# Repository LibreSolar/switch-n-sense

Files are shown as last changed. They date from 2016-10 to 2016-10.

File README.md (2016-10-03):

# Switch-N-Sense
High-side NMOS power switch and current sense resistor for battery applications

This device is the power part of the new generation Libre Solar 24V-48V BMS, but can also be used for lead-acid battery protection switches.

The connector to the BMS (IDC connector) is placed at the same height as in the BMS PCB. So mount this PCB right next to the BMS PCB (right side).

## Design considerations

The MOSFETs and the sense resistors are mounted at the back side of the PCB and should be attached to a large heat sink via thermal interface materials (e.g. thermal pad).

[Würth Power Elements WP-BUCF (order code 7461059)](https://powerelement.we-online.de/p/s/1406/93172-PowerOne-Bush-vertical-through-hole.html) are used for wire to board connection.

## Current target

Current rating can be adjusted depending on chosen MOSFETs and sense resistors.

- Maximum number of MOSFETs: 2 in parallel
- Maximum number of sense resitors (2512): 4

Targets for fully populated PCB (total heat dissipation approx. 20 W in MOSFETs, connectors and sense resistor at full current):

| MOSFET (2x) | Voltage | Maximum Current | Remark |
|---|---|---|---|
| FDMT80080DC | 48V | 80 A | |
| FDMT80060DC | 12V/24V | 100 A | |
| CSD18540Q5B | 12V/24V | 60 A | cheap alternative, but needs other footprint |

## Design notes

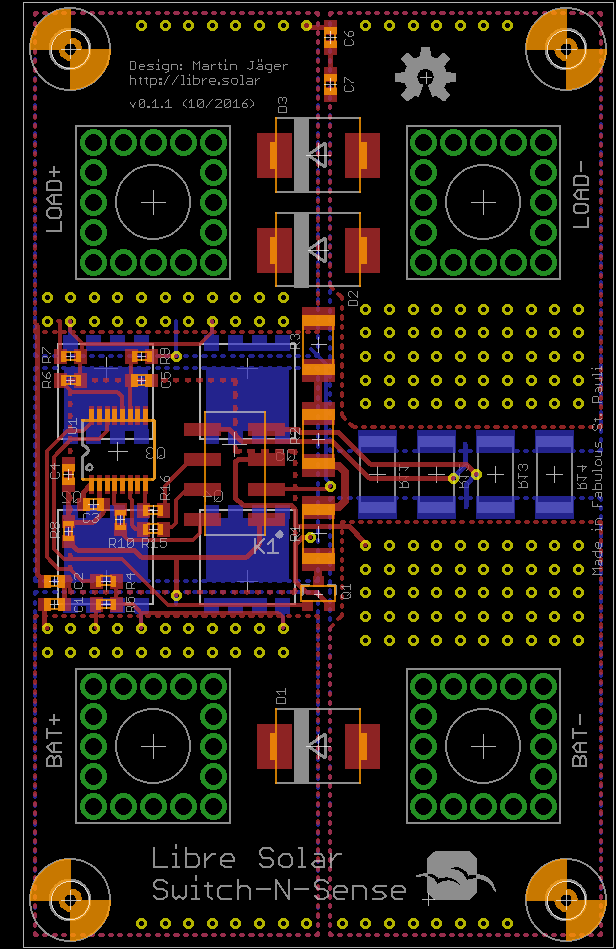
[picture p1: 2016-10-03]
Switch-N-Sense.png

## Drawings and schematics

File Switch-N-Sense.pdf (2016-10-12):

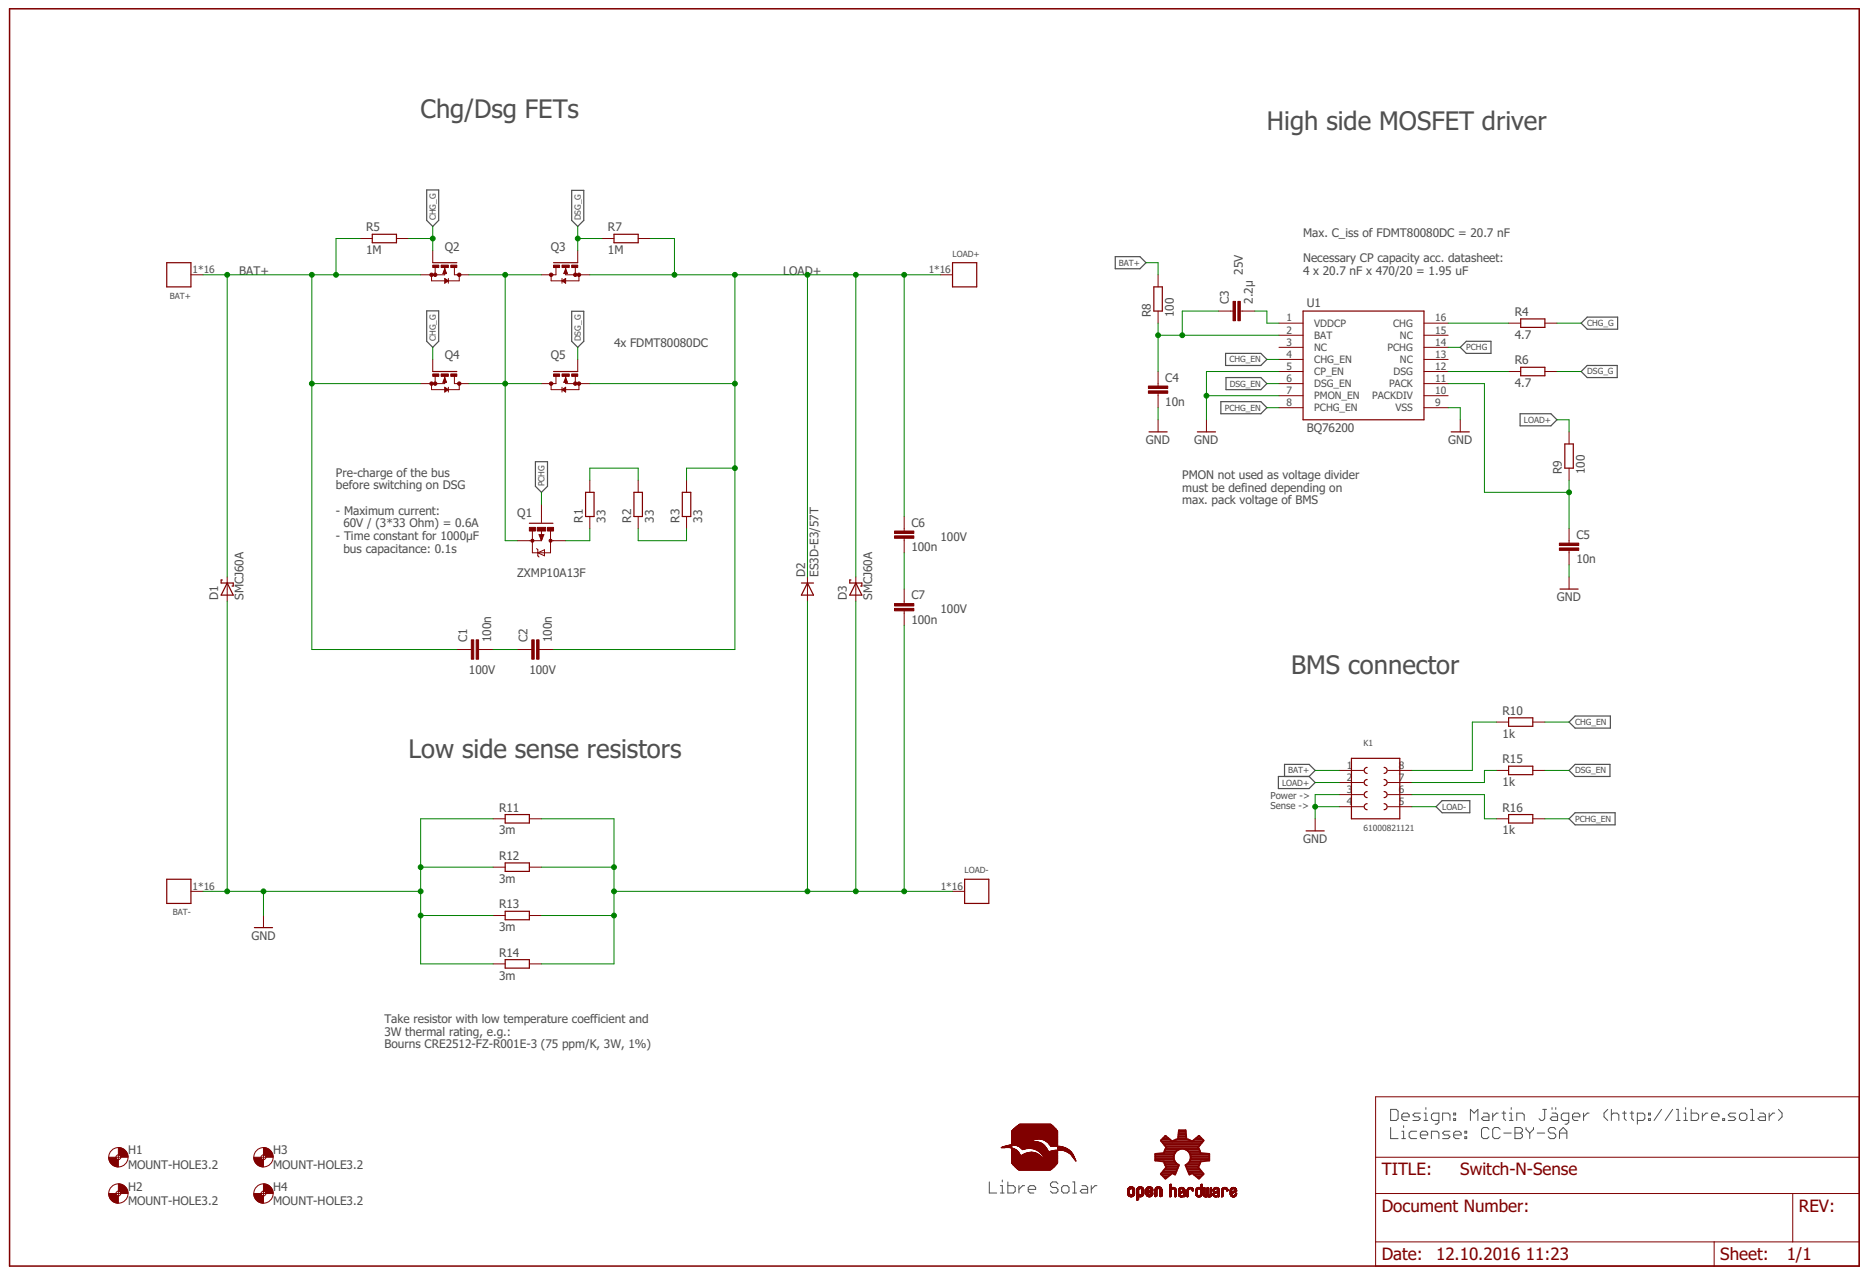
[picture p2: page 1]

Necessary CP capacity acc. datasheet: 4 x 20.7 nF x 470/20 = 1.95 uF

Pre-charge of the bus before switching on DSG

PMON not used as voltage divider must be defined depending on max. pack voltage of BMS

Low side sense resistors

Take resistor with low temperature coefficient and
3W thermal rating, e.g.: Bourns CRE2512-FZ-R001E-3 (75 ppm/K, 3W, 1%)

Document Number: | REV:

Date: 12.10.2016 11:23 | Sheet: 1/1

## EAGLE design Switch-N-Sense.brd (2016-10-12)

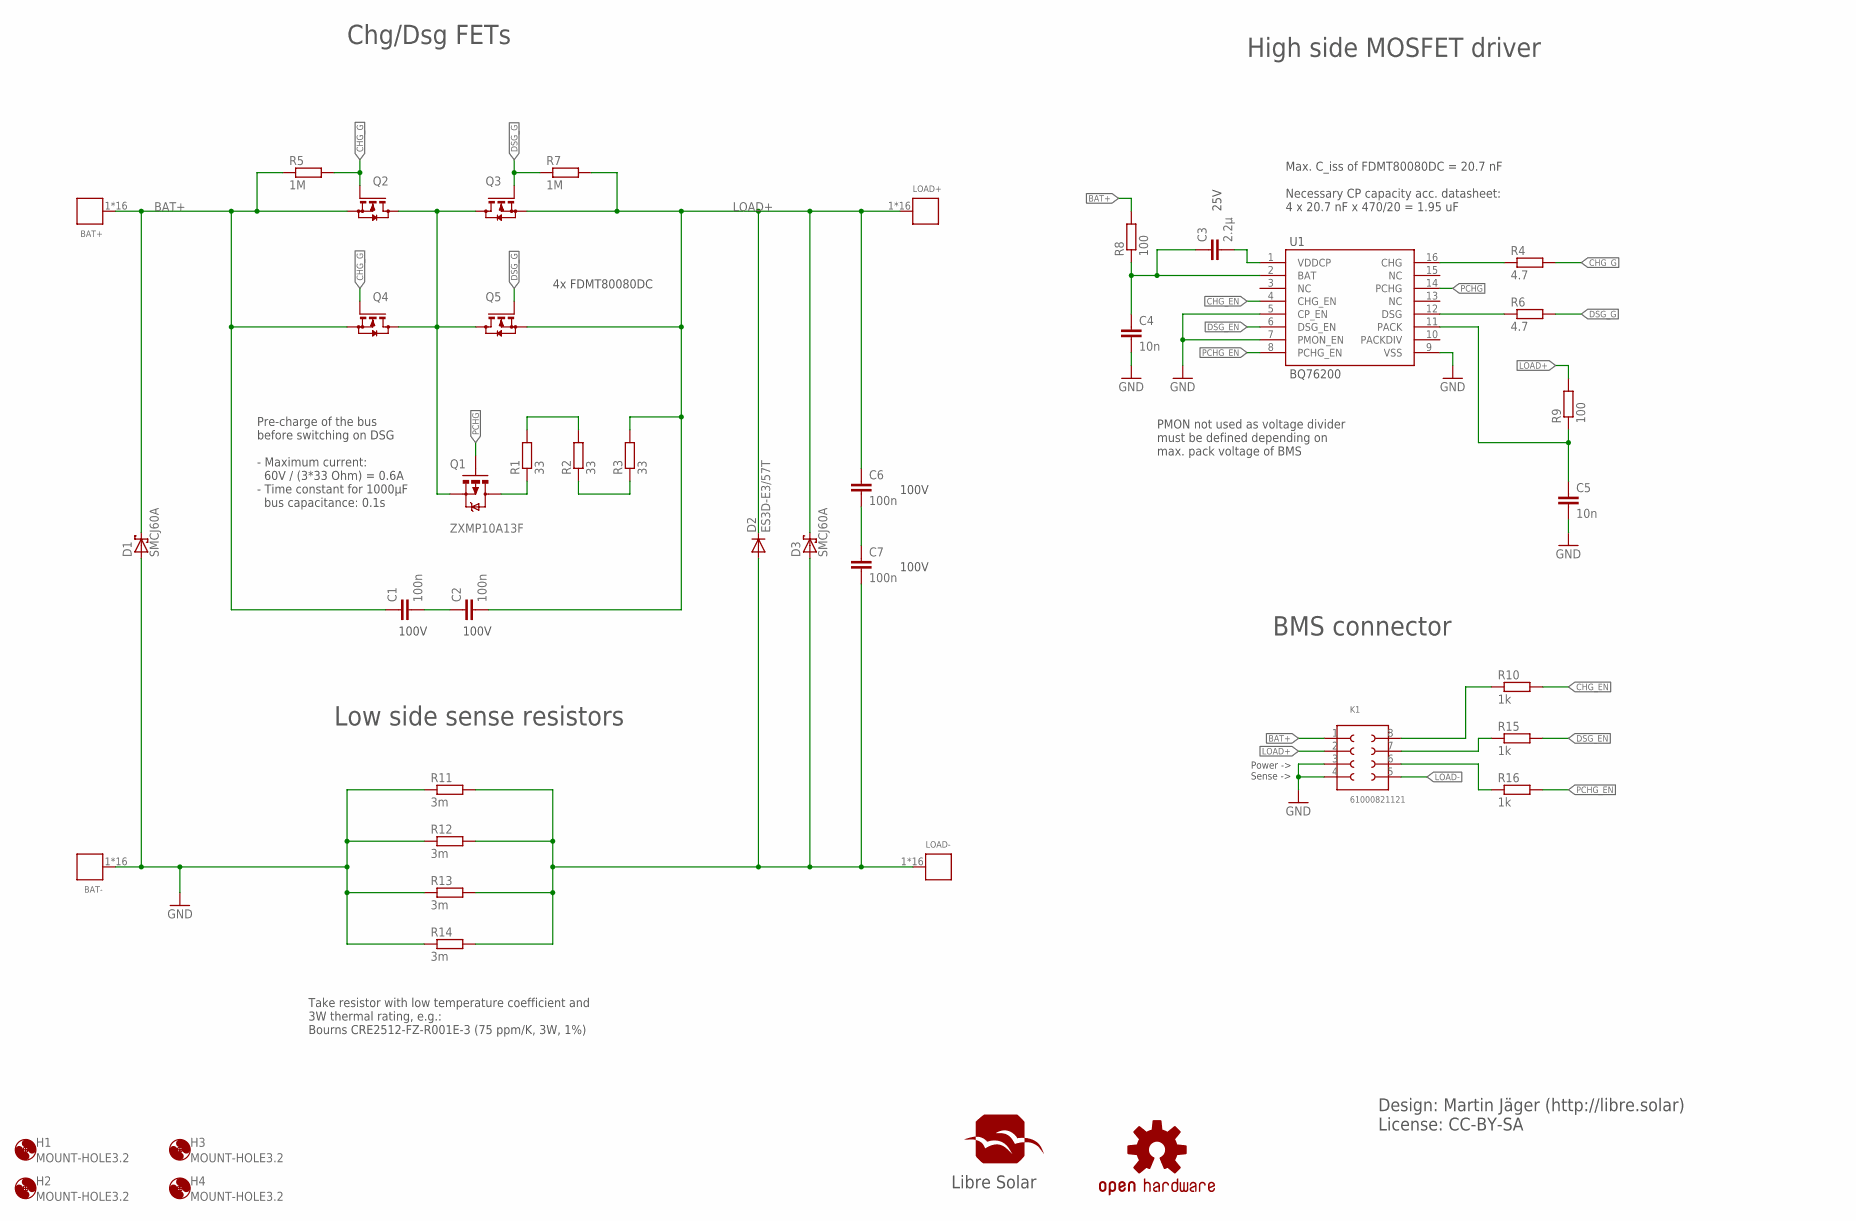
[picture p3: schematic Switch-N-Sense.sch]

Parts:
BAT+: WP-BUCF_G; 16PINS_CIR
BAT-: WP-BUCF_G; 16PINS_CIR
C1, C2, C6, C7: 100n; C0603; MPN 0603B104K500CT
C3: 2.2µ; C0805; MPN 0603B104K500CT
C4, C5: 10n; C0603; MPN GRM188R71H103KA01D.
D1, D3: SMCJ60A; SMC; MPN SMCJ75A
D2: ES3D-E3/57T; SMC; MPN ES3D-E3/57T.
H1, H2, H3, H4: MOUNT-HOLE3.2; 3,2
K1: 61000821121
LOAD+: WP-BUCF_G; 16PINS_CIR
LOAD-: WP-BUCF_G; 16PINS_CIR
N1: OSHW-LOGOM; OSHW-LOGO-M
Q1: ZXMP10A13F; SOT23-3; MPN ZXMP10A13FTA
Q2, Q3, Q4, Q5: FDMT80080DC
R1, R2, R3: 33; R2010; MPN ASC2010-33RFT4
R4, R6: 4.7; R0603; MPN ERJU06F1004V
R5, R7: 1M; R0603; MPN ERJU06F1004V
R8, R9: 100; R0603; MPN MCMR06X1001FTL
R10, R15, R16: 1k; R0603; MPN ERJU06F1004V
R11, R12, R13, R14: 3m; R2512
U1: BQ76200; TSSOP16
U$1: LIBRESOLAR_LOGO

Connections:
BAT+: BAT+.1, BAT+.2, BAT+.3, BAT+.4, BAT+.5, BAT+.6, BAT+.7, BAT+.8, BAT+.9, BAT+.10, BAT+.11, BAT+.12, BAT+.13, BAT+.14, BAT+.15, BAT+.16, C1.1, D1.C, K1.1, Q2.S, Q4.S, R5.1, R8.2
CHG: R4.1, U1.16 (CHG)
CHGDSG: Q1.2 (S), Q2.D, Q3.D, Q4.D, Q5.D
CHG_EN: R10.2, U1.4 (CHG_EN)
CHG_G: Q2.G, Q4.G, R4.2, R5.2
DSG: R6.1, U1.12 (DSG)
DSG_EN: R15.2, U1.6 (DSG_EN)
DSG_G: Q3.G, Q5.G, R6.2, R7.1
GND: BAT-.1, BAT-.2, BAT-.3, BAT-.4, BAT-.5, BAT-.6, BAT-.7, BAT-.8, BAT-.9, BAT-.10, BAT-.11, BAT-.12, BAT-.13, BAT-.14, BAT-.15, BAT-.16, C4.2, C5.2, D1.A, K1.3, K1.4, R11.1, R12.1, R13.1, R14.1, U1.5 (CP_EN), U1.7 (PMON_EN), U1.9 (VSS)
LOAD+: C2.2, C6.1, D2.C, D3.C, K1.2, LOAD+.1, LOAD+.2, LOAD+.3, LOAD+.4, LOAD+.5, LOAD+.6, LOAD+.7, LOAD+.8, LOAD+.9, LOAD+.10, LOAD+.11, LOAD+.12, LOAD+.13, LOAD+.14, LOAD+.15, LOAD+.16, Q3.S, Q5.S, R3.2, R7.2, R9.2
LOAD-: C7.2, D2.A, D3.A, K1.5, LOAD-.1, LOAD-.2, LOAD-.3, LOAD-.4, LOAD-.5, LOAD-.6, LOAD-.7, LOAD-.8, LOAD-.9, LOAD-.10, LOAD-.11, LOAD-.12, LOAD-.13, LOAD-.14, LOAD-.15, LOAD-.16, R11.2, R12.2, R13.2, R14.2
unnamed: C6.2, C7.1
unnamed: R1.2, R2.2
unnamed: R2.1, R3.1
unnamed: K1.7, R15.1
unnamed: K1.6, R16.1
unnamed: K1.8, R10.1
unnamed: C3.2, U1.1 (VDDCP)
unnamed: C3.1, C4.1, R8.1, U1.2 (BAT)
unnamed: C5.1, R9.1, U1.11 (PACK)
unnamed: C1.2, C2.1
unnamed: Q1.3 (D), R1.1
PCHG: Q1.1 (G), U1.14 (PCHG)
PCHG_EN: R16.2, U1.8 (PCHG_EN)

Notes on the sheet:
Pre-charge of the bus before switching on DSG - Maximum current: 60V / (3*33 Ohm) = 0.6A - Time constant for 1000µF bus capacitance: 0.1s
Chg/Dsg FETs
High side MOSFET driver
Design: Martin Jäger (http://libre.solar) License: CC-BY-SA
Max. C_iss of FDMT80080DC = 20.7 nF Necessary CP capacity acc. datasheet: 4 x 20.7 nF x 470/20 = 1.95 uF
4x FDMT80080DC
Take resistor with low temperature coefficient and 3W thermal rating, e.g.: Bourns CRE2512-FZ-R001E-3 (75 ppm/K, 3W, 1%)
Low side sense resistors
BMS connector
Power -> Sense ->
PMON not used as voltage divider must be defined depending on max. pack voltage of BMS
100V
25V

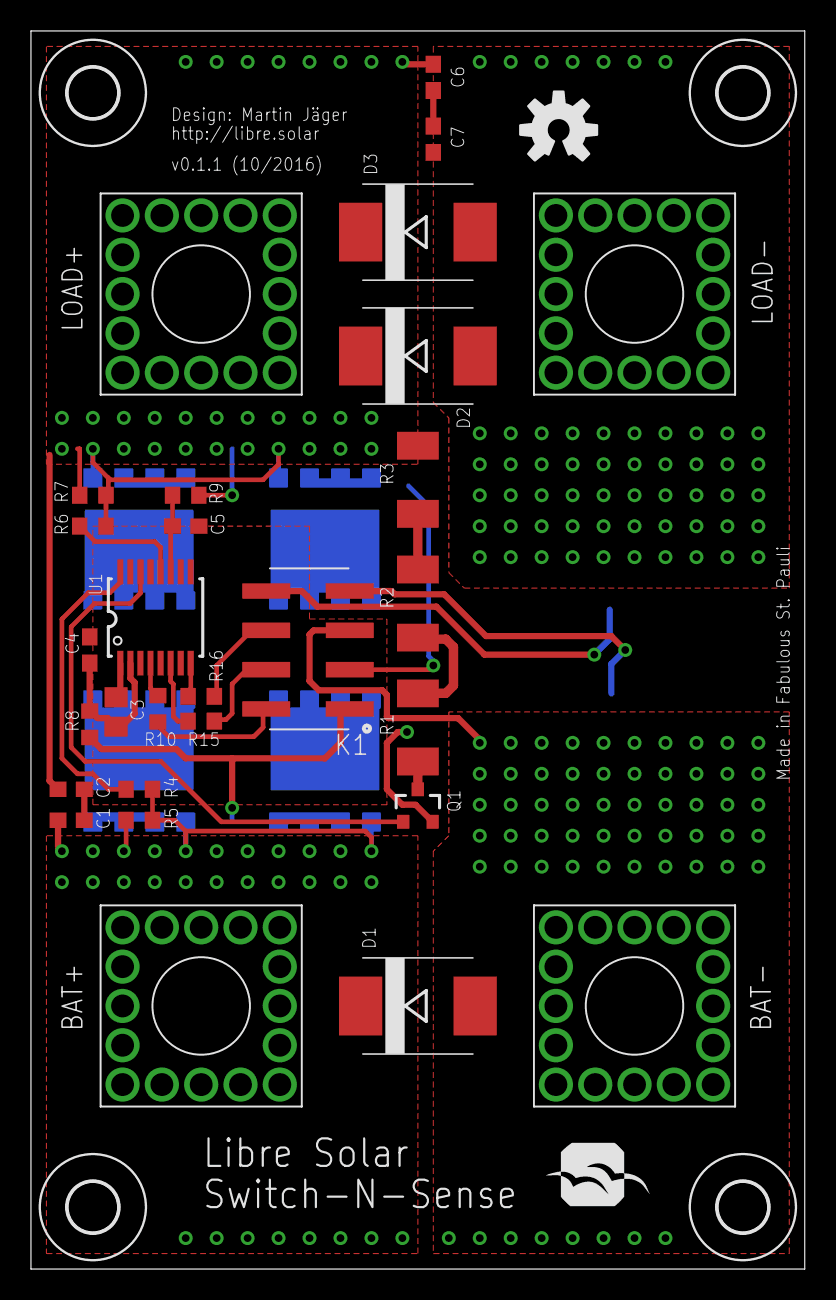
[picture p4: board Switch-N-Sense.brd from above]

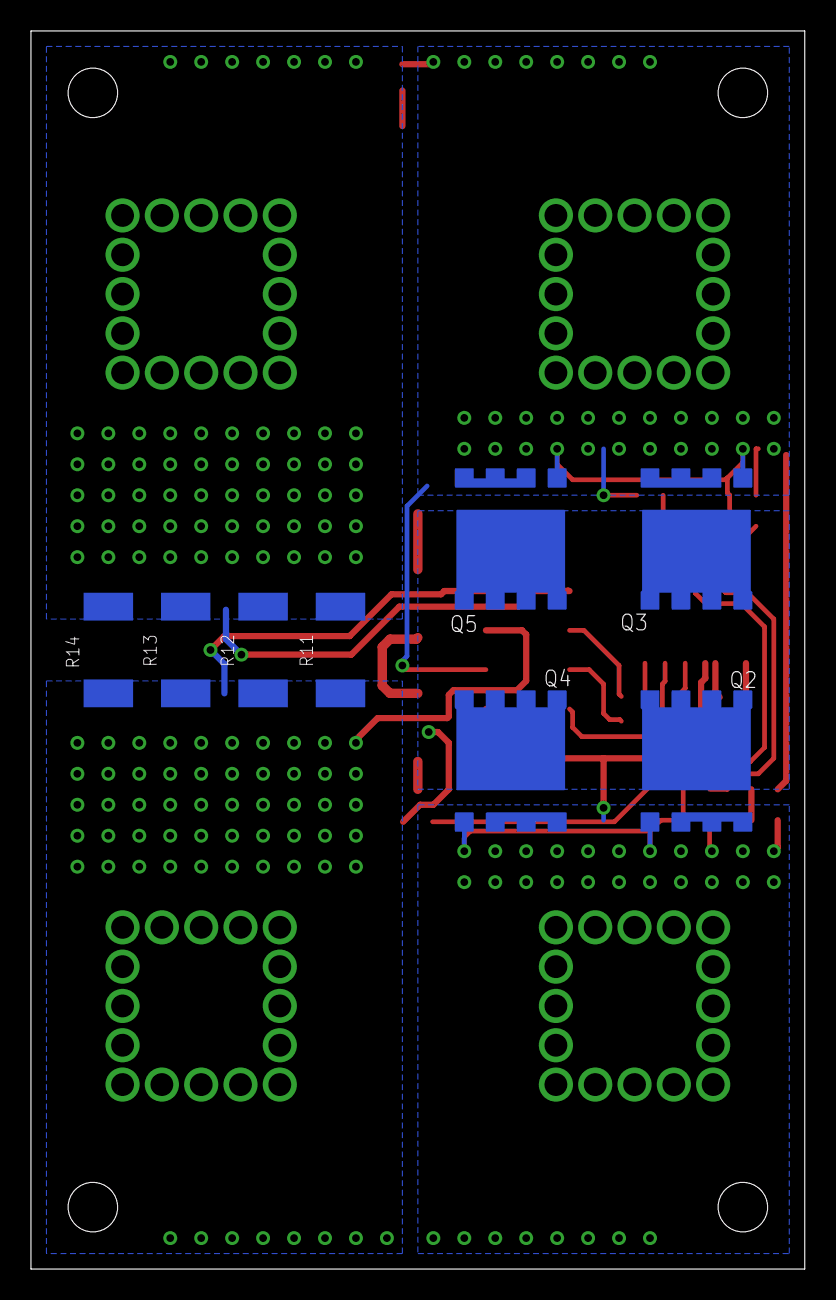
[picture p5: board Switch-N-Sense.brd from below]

Board: 2 copper layers, 50.0 x 80.0 mm, 43 parts (8 on the bottom side), 24 nets.

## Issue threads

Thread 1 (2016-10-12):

Package for C3 (VDDCP capacitor) too small

martinjaeger, 2016-10-12:
For 2.2uF part with 25V rating, at least 0805 package should be used instead of 0603.

martinjaeger, 2016-10-12:
Resolved with commit 094fc36

Closed 2016-10-12.

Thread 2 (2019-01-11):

Increase value of C3

martinjaeger, 2019-01-11:
If two MOSFETs in parallel are used, the value of 2.2 uF is borderline, which caused some issues with switching the MOSFETs during tests.

The capacitor should be increased to 4.7 uF.

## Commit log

2016-08-15 Initial commit of schematic and board
    [Switch-N-Sense.brd, Switch-N-Sense.sch]
2016-10-03 Update to mate with new LibreSolar BMS48V
    [Switch-N-Sense.brd, Switch-N-Sense.sch]
2016-10-12 Updated board and schematic to fix issue #1
    [Switch-N-Sense.brd, Switch-N-Sense.sch]

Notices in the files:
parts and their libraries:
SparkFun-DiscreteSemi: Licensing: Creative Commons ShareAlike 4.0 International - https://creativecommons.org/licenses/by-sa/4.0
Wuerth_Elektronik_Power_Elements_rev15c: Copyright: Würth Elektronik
